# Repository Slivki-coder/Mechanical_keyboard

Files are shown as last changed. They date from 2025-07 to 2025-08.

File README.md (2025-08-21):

# Keyboard

This is a Mechanical keyboard which I designed for highway, an event by hackclub. It includes a standard 80% layout as well as 5 macro keys on the left.

WhatsApp Bild 2025-08-21 um 10 07 07_0b671c8c

## CAD
I modeled all parts in Fusion 360. The case consists of 3 parts: The casing itself, a top plate for the switches and stabilizers and a stand to add a bit of incline to the keyboard. The stand and case each require 9 5x2mm magnets, which are used to attach the stand to the main body. It is also possible to add silicone feet to the stand to prevent it from sliding across the table. The top plate is fixed to the body with 7 M2.5x10 screws.









## PCB
The PCB & schematic was designed in KiCAD. The schematic is a bit confusing because some keys from col13 are shfted up one row.




## Firmware
The Firmware was created in python using the kmk library. It requires Circuitpython to be installed on the mcu to run. The Macro functions are currently empty, these can be set to any macro you want. KMK also does not have a Menu key so this one is currently set to KC.NO, but it can be repurposed as a layer switch for example.

## BOM

| Item | Amount | Total Price | Required |
|---|---|---|---|
| Neodymium Magnet 5x2mm  | 18  | 8€  | Yes |
| Rubber Pad 10mm | 2  | 4€  | Yes |
| M2.5x10 screw  | 7  | 11€  | Yes |
| Cherry MX switches | 92 | 75€ | Yes |
| Keycaps | 92 | 30€ | Yes |
| PCB | 1 | / | Yes |
| Raspberry Pi Pico | 1 | 10€ | Yes |
| 3d Printing Filament (any) | 1 spool | ~20€ | No |
| **Total** | | 158€ |

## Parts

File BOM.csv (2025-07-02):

Part | Amount | Cost | Link
Neodymium Magnet | 5x2mm | 7 | 7€ | https://amzn.eu/d/3slAySB
Rubber Pad | 10mm | 2 | 4€ | https://amzn.eu/d/7RgwESr
M2.5x10 screw | 7 | 11€ | https://amzn.eu/d/3ODUxXx
Cherry MX switches | 92 | 75€ | https://shop.cherry.de/mx-rgb-black-switch-kit.html
Keycaps | 92 | 25€ | https://amzn.eu/d/aOeOemJ
PCB | 1 | 50€ | jlcpcb.com
RPI Pico | 1 | 17€ | https://amzn.eu/d/3SUL29R
Filament/3d printed case | 1 | 24€ | https://amzn.eu/d/eSc6kCR

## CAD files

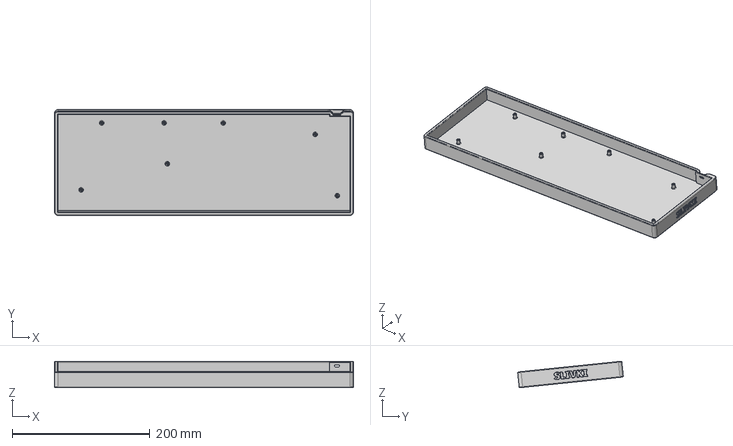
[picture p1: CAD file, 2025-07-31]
CAD/keyboard_body.step
433.5 x 153.2 x 38.3 mm

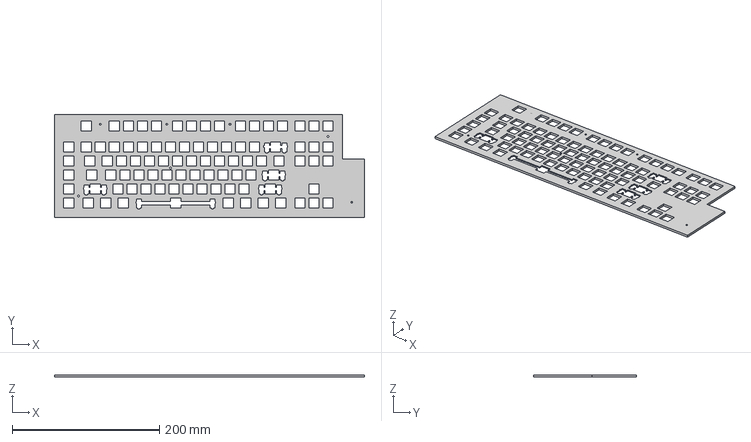
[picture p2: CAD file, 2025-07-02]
production/keyboard_top_plate.step
421.5 x 139.8 x 3.00 mm

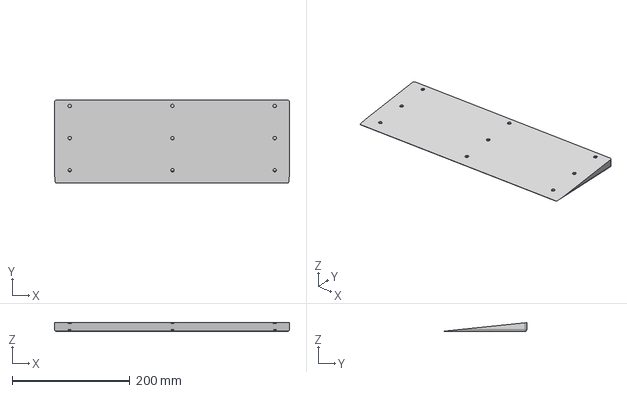
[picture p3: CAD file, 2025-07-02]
production/keyboard_stand.step
400.0 x 140.7 x 15.0 mm

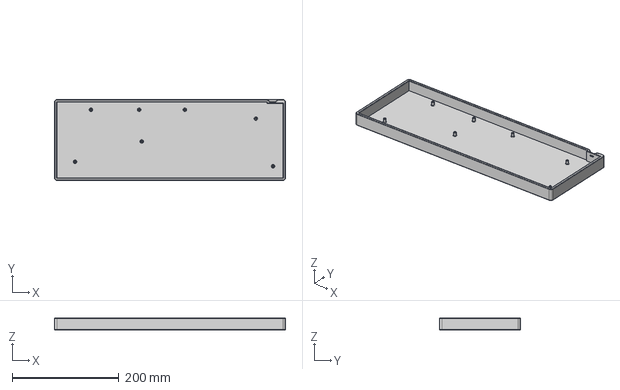
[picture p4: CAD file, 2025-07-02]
production/keyboard_case.step
433.5 x 151.8 x 23.0 mm

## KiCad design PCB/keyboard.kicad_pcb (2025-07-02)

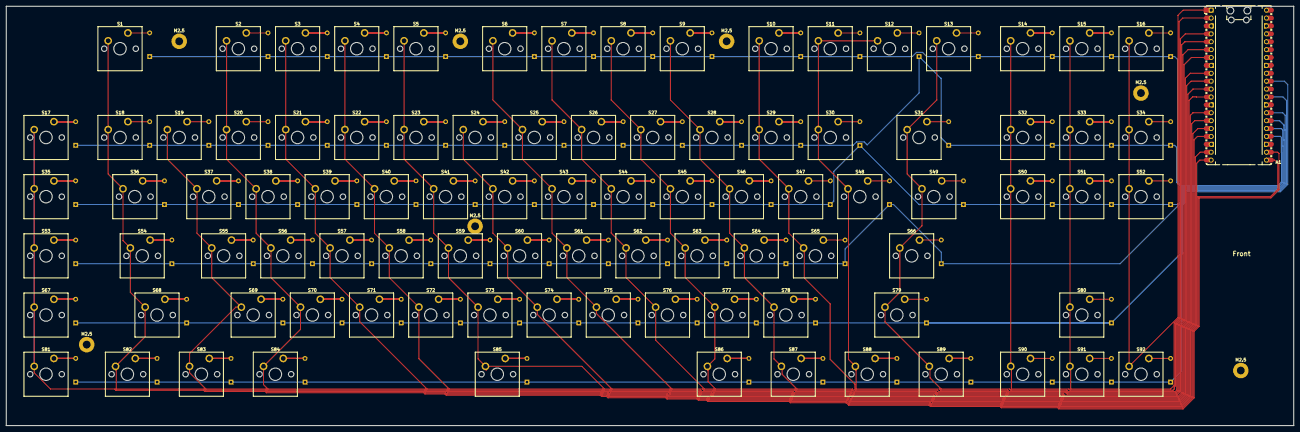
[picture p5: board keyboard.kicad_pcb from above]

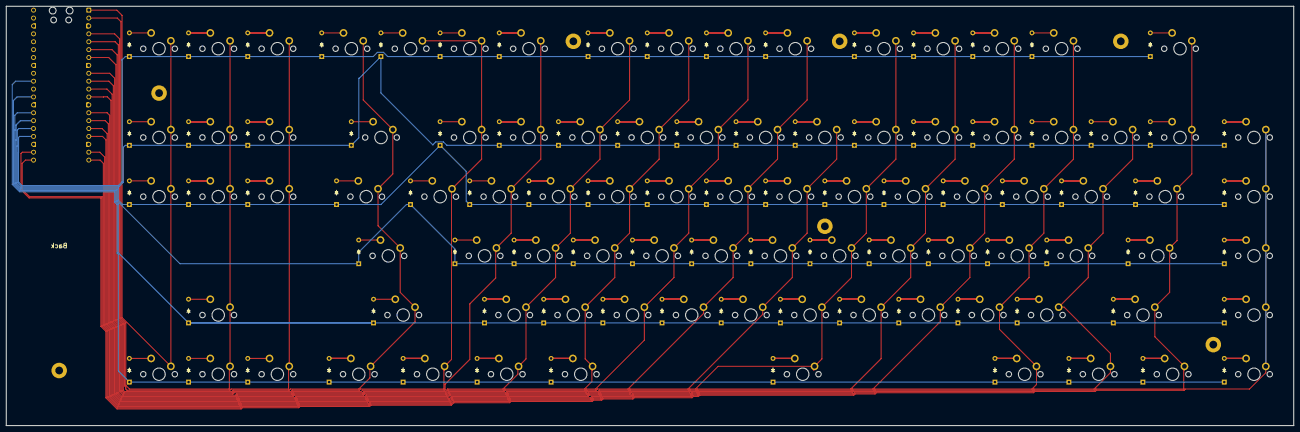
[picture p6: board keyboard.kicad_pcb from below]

Board: 2 copper layers, 414.4 x 135.0 mm, 192 parts (92 on the bottom side), 117 nets.

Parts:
A1: RaspberryPi_Pico; RaspberryPi_Pico_Common_Unspecified
D1, D2, D3, D4, D5, D6, D7, D8, D9, D10, D11, D12, D13, D14, D15, D16, D17, D18, D19, D20, D21, D22, D23, D24, D25, D26, D27, D28, D29, D30, D31, D32, D33, D34, D35, D36, D37, D38, D39, D40, D41, D42, D43, D44, D45, D46, D47, D48, D49, D50, D51, D52, D53, D54, D55, D56, D57, D58, D59, D60, D61, D62, D63, D64, D65, D66, D67, D68, D69, D70, D71, D72, D73, D74, D75, D76, D77, D78, D79, D80, D81, D82, D83, D84, D85, D86, D87, D88, D89, D90, D91, D92: Diode; Diode_DO-35
M2.5, M2.5#2, M2.5#3, M2.5#4, M2.5#5, M2.5#6, M2.5#7: MountingHole_2.5mm_Pad
S1, S2, S3, S4, S5, S6, S7, S8, S9, S10, S11, S12, S13, S14, S15, S16, S17, S18, S19, S20, S21, S22, S23, S24, S25, S26, S27, S28, S29, S30, S31, S32, S33, S34, S35, S36, S37, S38, S39, S40, S41, S42, S43, S44, S45, S46, S47, S48, S49, S50, S51, S52, S53, S54, S55, S56, S57, S58, S59, S60, S61, S62, S63, S64, S65, S66, S67, S68, S69, S70, S71, S72, S73, S74, S75, S76, S77, S78, S79, S80, S81, S82, S83, S84, S85, S86, S87, S88, S89, S90, S91, S92: Keyswitch; MX_PCB_1.00u

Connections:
unnamed: A1.3 (GND), A1.8 (GND), A1.13 (GND), A1.18 (GND), A1.23 (GND), A1.28 (GND), A1.38 (GND)
unnamed: D1.2 (A), S1.2
unnamed: D2.2 (A), S2.2
unnamed: D3.2 (A), S3.2
unnamed: D4.2 (A), S4.2
unnamed: D5.2 (A), S5.2
unnamed: D6.2 (A), S6.2
unnamed: D7.2 (A), S7.2
unnamed: D8.2 (A), S8.2
unnamed: D9.2 (A), S9.2
unnamed: D10.2 (A), S10.2
unnamed: D11.2 (A), S11.2
unnamed: D12.2 (A), S12.2
unnamed: D13.2 (A), S13.2
unnamed: D14.2 (A), S14.2
unnamed: D15.2 (A), S15.2
unnamed: D16.2 (A), S16.2
unnamed: D17.2 (A), S17.2
unnamed: D18.2 (A), S18.2
unnamed: D19.2 (A), S19.2
unnamed: D20.2 (A), S20.2
unnamed: D21.2 (A), S21.2
unnamed: D22.2 (A), S22.2
unnamed: D23.2 (A), S23.2
unnamed: D24.2 (A), S24.2
unnamed: D25.2 (A), S25.2
unnamed: D26.2 (A), S26.2
unnamed: D27.2 (A), S27.2
unnamed: D28.2 (A), S28.2
unnamed: D29.2 (A), S29.2
unnamed: D30.2 (A), S30.2
unnamed: D31.2 (A), S31.2
unnamed: D32.2 (A), S32.2
unnamed: D33.2 (A), S33.2
unnamed: D34.2 (A), S34.2
unnamed: D35.2 (A), S35.2
unnamed: D36.2 (A), S36.2
unnamed: D37.2 (A), S37.2
unnamed: D38.2 (A), S38.2
unnamed: D39.2 (A), S39.2
unnamed: D40.2 (A), S40.2
unnamed: D41.2 (A), S41.2
unnamed: D42.2 (A), S42.2
unnamed: D43.2 (A), S43.2
unnamed: D44.2 (A), S44.2
unnamed: D45.2 (A), S45.2
unnamed: D46.2 (A), S46.2
unnamed: D47.2 (A), S47.2
unnamed: D48.2 (A), S48.2
unnamed: D49.2 (A), S49.2
unnamed: D50.2 (A), S50.2
unnamed: D51.2 (A), S51.2
unnamed: D52.2 (A), S52.2
unnamed: D53.2 (A), S53.2
unnamed: D54.2 (A), S54.2
unnamed: D55.2 (A), S55.2
unnamed: D56.2 (A), S56.2
unnamed: D57.2 (A), S57.2
unnamed: D58.2 (A), S58.2
unnamed: D59.2 (A), S59.2
unnamed: D60.2 (A), S60.2
unnamed: D61.2 (A), S61.2
unnamed: D62.2 (A), S62.2
unnamed: D63.2 (A), S63.2
unnamed: D64.2 (A), S64.2
unnamed: D65.2 (A), S65.2
unnamed: D66.2 (A), S66.2
unnamed: D67.2 (A), S67.2
unnamed: D68.2 (A), S68.2
unnamed: D69.2 (A), S69.2
unnamed: D70.2 (A), S70.2
unnamed: D71.2 (A), S71.2
unnamed: D72.2 (A), S72.2
unnamed: D73.2 (A), S73.2
unnamed: D74.2 (A), S74.2
unnamed: D75.2 (A), S75.2
unnamed: D76.2 (A), S76.2
unnamed: D77.2 (A), S77.2
unnamed: D78.2 (A), S78.2
unnamed: D79.2 (A), S79.2
unnamed: D80.2 (A), S80.2
unnamed: D81.2 (A), S81.2
unnamed: D82.2 (A), S82.2
unnamed: D83.2 (A), S83.2
unnamed: D84.2 (A), S84.2
unnamed: D85.2 (A), S85.2
unnamed: D86.2 (A), S86.2
unnamed: D87.2 (A), S87.2
unnamed: D88.2 (A), S88.2
unnamed: D89.2 (A), S89.2
unnamed: D90.2 (A), S90.2
unnamed: D91.2 (A), S91.2
unnamed: D92.2 (A), S92.2
col0: A1.22 (GPIO17), S17.1, S35.1, S53.1, S67.1, S81.1
col1: A1.21 (GPIO16), S1.1, S18.1, S36.1, S54.1, S68.1, S82.1
col2: A1.20 (GPIO15), S19.1, S37.1, S55.1, S69.1, S83.1
col3: A1.19 (GPIO14), S2.1, S20.1, S38.1, S56.1, S70.1, S84.1
col4: A1.17 (GPIO13), S3.1, S21.1, S39.1, S57.1, S71.1
col5: A1.16 (GPIO12), S4.1, S22.1, S40.1, S58.1, S72.1
col6: A1.15 (GPIO11), S5.1, S23.1, S41.1, S59.1, S73.1, S85.1
col7: A1.14 (GPIO10), S24.1, S42.1, S60.1, S74.1
col8: A1.12 (GPIO9), S6.1, S25.1, S43.1, S61.1, S75.1
col9: A1.11 (GPIO8), S7.1, S26.1, S44.1, S62.1, S76.1
col10: A1.10 (GPIO7), S8.1, S27.1, S45.1, S63.1, S77.1, S86.1
col11: A1.9 (GPIO6), S9.1, S28.1, S46.1, S64.1, S78.1, S87.1
col12: A1.7 (GPIO5), S10.1, S29.1, S47.1, S65.1
col13: A1.6 (GPIO4), S11.1, S12.1, S30.1, S48.1, S88.1
col14: A1.5 (GPIO3), S13.1, S31.1, S49.1, S66.1, S79.1, S89.1
col15: A1.4 (GPIO2), S14.1, S32.1, S50.1, S90.1
col16: A1.2 (GPIO1), S15.1, S33.1, S51.1, S80.1, S91.1
col17: A1.1 (GPIO0), S16.1, S34.1, S52.1, S92.1
row0: A1.24 (GPIO18), D1.1 (K), D2.1 (K), D3.1 (K), D4.1 (K), D5.1 (K), D6.1 (K), D7.1 (K), D8.1 (K), D9.1 (K), D10.1 (K), D11.1 (K), D13.1 (K), D14.1 (K), D15.1 (K), D16.1 (K)
row1: A1.25 (GPIO19), D12.1 (K), D17.1 (K), D18.1 (K), D19.1 (K), D20.1 (K), D21.1 (K), D22.1 (K), D23.1 (K), D24.1 (K), D25.1 (K), D26.1 (K), D27.1 (K), D28.1 (K), D29.1 (K), D31.1 (K), D32.1 (K), D33.1 (K), D34.1 (K)
row2: A1.26 (GPIO20), D30.1 (K), D35.1 (K), D36.1 (K), D37.1 (K), D38.1 (K), D39.1 (K), D40.1 (K), D41.1 (K), D42.1 (K), D43.1 (K), D44.1 (K), D45.1 (K), D46.1 (K), D47.1 (K), D49.1 (K), D50.1 (K), D51.1 (K), D52.1 (K)
row3: A1.27 (GPIO21), D48.1 (K), D53.1 (K), D54.1 (K), D55.1 (K), D56.1 (K), D57.1 (K), D58.1 (K), D59.1 (K), D60.1 (K), D61.1 (K), D62.1 (K), D63.1 (K), D64.1 (K), D65.1 (K), D66.1 (K)
row4: A1.29 (GPIO22), D67.1 (K), D68.1 (K), D69.1 (K), D70.1 (K), D71.1 (K), D72.1 (K), D73.1 (K), D74.1 (K), D75.1 (K), D76.1 (K), D77.1 (K), D78.1 (K), D79.1 (K), D80.1 (K)
row5: A1.31 (GPIO26_ADC0), D81.1 (K), D82.1 (K), D83.1 (K), D84.1 (K), D85.1 (K), D86.1 (K), D87.1 (K), D88.1 (K), D89.1 (K), D90.1 (K), D91.1 (K), D92.1 (K)

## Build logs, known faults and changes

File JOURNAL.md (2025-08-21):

---
title: "Oliver_QMK_keyboard"
author: "Oliver  Lacika"
description: "A custom designed mechanical keyboard. Not sure yet if I will be able to add any features like rbg or rotary knobs"
created_at: "2025-06-26"
Total Time: "~50hours"
---
# June 26th: Started working on the pcb, mainly the schematic.

I watched and read a few tutorials on how to design a keyboard before beginning to do so myself. I tried multiple approaches, for example using an STM32 microchip for controlling, but that seemed too complicated for my skill level, and since I didnt want to copy someone else's work, I opted for using the raspberry pi pico. After this, I designed the schematic.



**Total time spent: 5h**
# June 27th: Finished wiring the PCB

I wired all the switches on my PCB to my controller



**Total time spent: 8h**
# June 29th: Redesigned everything because the pcb was too messy

My previous attempt required 4 layers, had traces going everywhere and like 5 vias per trace. Because of that, I decided to redesign my schematic (this time keeping the final layout in mind) and then also completely redo the PCB. Now I only need 2 layers, 0 vias and the traces are pretty organised.




**Total time spent: 6h**
# June 30th: Started working on the 3d model

I started working on the case for the keyboard. I finished the top plate and also started working on the main casing. (The screenshots were made on a later date since I forgot to take them at that time, so some changes may be present which I added a day later)




**Total time spent: 8h**
# July 1st: Finished 3d modeling and created the firmware

I finished the 3d model of the case and added a stand to add a 6 degree slope to it. I also added small holes on the bottom of the case and the stand for magnets which are supposed to hold the 2 parts together, and slightly larger holes on the bottom of the stand to add silicone pads to stop it from sliding across the table.





**Total time spent: 6h**
# July 29th-31st: Added a logo and Name

I created an SVG logo and added it to the bottom of the stand, and also added my nickname (slivki) to the side of the main body. I then spnet a lot of time making sure the logo is printable (due to the overhandds created when printing vertically) which turned out to take much more time than expected




**Total time spent: 6h**
# August 18th: Started building the keyboard

I 3d printed all the files, and once the parts arrived from amazon, I started roughly assembling the keyboard

WhatsApp Bild 2025-08-21 um 10 11 58_63fd9120
WhatsApp Bild 2025-08-21 um 10 11 58_f0bbc097
WhatsApp Bild 2025-08-21 um 10 11 58_a23e7fb0

**Total time spent: 5h**
# August 19th: assembled the keyboard with the parts I already had, reprinted some parts

I connected the 2 parts of the main body of the keyboard, spray painted some screws to be less visible, and assembled the keyboard, but without the pcb since I did not have it yet.

WhatsApp Bild 2025-08-21 um 10 11 58_49705b1e

**Total time spent: 4h**
# August 20th: assembled the pcb, uploaded firmware, etc. (finished project)

I finally received the pcb and soldered all components to it, uploaded the firmware to rpi pico, the did some minor debugging of both the hardware and the software




**Total time spent: 7h**

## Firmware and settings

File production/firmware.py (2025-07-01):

from kmk.kmk_keyboard import KMKKeyboard # type: ignore
from kmk.keys import KC                  # type: ignore
from kmk.scanners import DiodeOrientation# type: ignore
from kmk.key import Key                  # type: ignore
import board                             # type: ignore

from kmk.modules.layers import Layers    # type: ignore

keyboard = KMKKeyboard()

# Add layer support
keyboard.modules.append(Layers())

# Define matrix row and column pins
keyboard.row_pins = (board.GP18, board.GP19, board.GP20, board.GP21, board.GP22, board.GP26)
keyboard.col_pins = (board.GP17, board.GP16, board.GP15, board.GP14, board.GP13, board.GP12, board.GP11, board.GP10, board.GP9, board.GP8, board.GP7, board.GP6, board.GP5, board.GP4, board.GP3, board.GP2, board.GP1, board.GP0)

# Specify diode direction (most keyboards are COL2ROW)
keyboard.diode_orientation = DiodeOrientation.COL2ROW

def macro_1(key, keyboard, *args):
    return False
def macro_2(key, keyboard, *args):
    return False
def macro_3(key, keyboard, *args):
    return False
def macro_4(key, keyboard, *args):
    return False
def macro_5(key, keyboard, *args):
    return False

KC_M1 = Key(macro_1)
KC_M2 = Key(macro_2)
KC_M3 = Key(macro_3)
KC_M4 = Key(macro_4)
KC_M5 = Key(macro_5)


# Define keymap layout (4 rows x 3 columns in this example)
keyboard.keymap = [
    [
        KC.NO, KC.ESC,   KC.NO,   KC.F1,   KC.F2, KC.F3, KC.F4,    KC.NO, KC.F5, KC.F6,   KC.F7,   KC.F8,   KC.F9,   KC.F10,  KC.F12,  KC.PRNT, KC.SLCK, KC.PAUS,
        KC_M1, KC.GRAVE, KC._1,   KC._2,   KC._3, KC._4, KC._5,    KC._6, KC._7, KC._8,   KC._9,   KC._0,   KC.MINS, KC.F11,  KC.BSPC, KC.INS,  KC.HOME, KC.PGUP,
        KC_M2, KC.TAB,   KC.Q,    KC.W,    KC.E,  KC.R,  KC.T,     KC.Y,  KC.U,  KC.I,    KC.O,    KC.P,    KC.LBRC, KC.EQL,  KC.BSLS, KC.DEL,  KC.END,  KC.PGDN,
        KC_M3, KC.CAPS,  KC.A,    KC.S,    KC.D,  KC.F,  KC.G,     KC.H,  KC.J,  KC.K,    KC.L,    KC.SCLN, KC.QUOT, KC.RBRC, KC.ENT,  KC.NO,   KC.NO,   KC.NO,
        KC_M4, KC.LSFT,  KC.Z,    KC.X,    KC.C,  KC.V,  KC.B,     KC.N,  KC.M,  KC.COMM, KC.DOT,  KC.SLSH, KC.NO,   KC.NO,   KC.RSFT, KC.NO,   KC.UP,   KC.NO,
        KC_M5, KC.LCTL,  KC.LGUI, KC.LALT, KC.NO, KC.NO, KC.SPACE, KC.NO, KC.NO, KC.NO,   KC.RALT, KC.RGUI, KC.NO,   KC.RCTL, KC.LEFT, KC.DOWN, KC.RIGHT


    ]
]

if __name__ == '__main__':
    keyboard.go()

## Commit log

2025-07-02 added all files, updated README
    [keyboard.kicad_pcb, keyboard.kicad_sch, keyboard_case.step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]
2025-07-02 added BOM file
    [BOM.csv]
2025-07-18 Added fusion project file
    [keyboard.f3z]
2025-07-18 Please enter the commit message for your changes. Lines starting moved file into correct folder
    [keyboard.f3z]
2025-07-31 Updated files
    [keyboard_body.step]
